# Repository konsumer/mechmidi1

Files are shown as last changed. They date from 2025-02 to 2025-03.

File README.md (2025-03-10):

This is a [RP2040-Zero](https://www.waveshare.com/rp2040-zero.htm) mechanical keyboard I designed to be a MIDI controller/sequencer and/or macro-keypad. It's made to be highly configurable & easy to modify.

> [!CAUTION]
> After assembling, I think the keys are a tiny bit too close together (spacing left/right should be doubled) and I think the RP2040 needs a board-cutout to make it lay flush. You can solder it as it is, but it makes it much harder, because it has a gap between the boards. I am currently reworking the design in Kicad, and will attempt to test another iteration.

## Features

- 20-key keypad with MX-style switches
- OLED 128x64 display
- 2 rotary encoders (each with a button)
- 20 RGB LEDs
- i2c port for adding more stuff (for example I might make a dongle for bluetooth or USB midi/keyboard/mouse/gamepad host)
- old-school MIDI in/out
- I used pi 2040, but you can use any chip, with a little modification
- designed to be easy to reflow-solder with a toaster oven, if you are manufacturing/assembling yourself
- Fully programmable with [CircuitPython](https://circuitpython.org/)
- Use [KMK](https://github.com/KMKfw/kmk_firmware) for a more keyboard-focused python-programmable firmware
- Use MIDI-focused firmware over USB, or with oldschool MIDI-out, that does sequencing
- translate USB MIDI to oldschool MIDI (no USB host, but it can interact with computer)
- pattern/song/track sequencer for sequencing drums
- pattern/song/track sequencer for sequencing notes
- arpeggio sequencer

## build/install

- order PCB & parts. Feel free to use whatever cheaper parts you can find. It pays to look around, especially with the OLED and LED chips. The key-switches are also totally up to you, but I recommend something clear, so the light shines through better. You will also need keycaps (again, clear or matte white looks nice)
- if you want to use easyeda & [jlcpcb](https://jlcpcb.com/) (it's very cheap & easy) you can disable any parts you don't need/want in BOM, and it will leave them out. For example, I didn't use the keys or 2040 they listed, I used my own (and it ended up better, I think.)
- solder components on board. [this](https://learn.sparkfun.com/tutorials/how-to-solder-castellated-mounting-holes/all) was helpful for the RP2040-Zero. Flux really helps, and a cheap USB microscope, if you have one. Basically, I fluxed it up, put a pointy tipped iron in slot, then added a lil solder, for each pin. If you are soldering the other parts, it should be easier with a toaster/hotplate, since all the parts are on one side.
- if you want classic MIDI, connect a board, like [this](https://www.amazon.com/ubld-itTM-Breakout-Board-Multi-Voltage/dp/B0BYMC926Z) to "expansion port" on board. I did this as a seperate board because I had a MIDI breakout-board laying around and I wanted it all to fit on a very small main-board. Another trick is sometimes the MIDI ports are included with other features on the board. For example [this](https://shop.m5stack.com/products/midi-unit-with-din-connector-sam2695) has MIDI DIN IN/OUT, as well as TRS MIDI ports, and has a full sound-engine built in (entire General Midi of 128 decent-sounding instruments.) Even if you don't want the sounds, the MIDI connections alone are useful, but with sounds, it makes the device even cooler!
- [install circuitpython](https://circuitpython.org/board/waveshare_rp2040_zero/) and any [libs](https://circuitpython.org/libraries) you need to "circuitpython" disk, in lib dir. You can skip this if you want arduino or some other firmware, but circuitpython is recommended initially, to test things, easily. For me, the whole circuitpython bundle was too big, so just copy [firmware](firmware). My code.py is meant to test each part initially (so you can make sure hardware/software is setup right.) I also included a lib dir, so you shouldn;t need anything else, to get started.
- move sequencer.py to code.py, and reboot, and you should have a complete device.

### expansion & hardware

At the top-left of board, there is an expansion port for MIDI/serial/i2c/power.

ports

```
[GND] (3V3) (TX) (RX) (SCL) (SDA)
```

Use this to hook up classic midi daughter-board, or any other i2c/serial thing you want.

If you need to access these pins in code or want to expand the board, here is how they are hooked up to the RP2040-Zero:

pinout

- `VCC` (3.3V) and `GND` are power. I did not expose `5V`, but you could add it to expansion-port, or you can just add a bodge-wire to chip-pin or one of the through-holes on board, if you need that. IO is best at `3.3V` for this chip, so I wanted to keep it all "easy to stay safe"
- `LED` is a neopixel-line (has 20 RGB LEDs on it, but you can add many more.) Again, a bodge-wire will be needed to add more pixels to this line, but it's fairly easy to solder one on, if you need that.
- `COL(X)`/`ROW(X)` are the keyboard-matrix
- `ROT(X)A`/`ROT(X)B`/`ROT(X)S` are the rotary-encoders (`S` is the push-down switch)
- `SDA`/`SCL` is i2c. You can add up to 127 devices to this bus (each has it's own address, and they share wires) but OLED takes up 1 slot
- `RX`/`TX` is serial or classic MIDI (with a little circuit)

### cost

You can definitely find these cheaper, if you look around. Although it's cheaper than any nice MIDI controller/sequencer/synth I found, that did what I want, super-cheap was not really a goal for me, with this project. It could be done differently, and much cheaper, I just wanted everything to work just like this, and be pretty quick/easy to assemble (it's a gift for a young-person, with not too much soldering experience.)

If you do it all my way, the per-unit cost is about $40, not including addons or whatever. A [nice midi & sound addon](https://shop.m5stack.com/products/midi-unit-with-din-connector-sam2695) is another $15.

- board with assembly - a bit cheaper in bulk, with assembly. I ordered 10, at $16 each (including shipping) and it has most of the parts on the board (no RP2040 or keys.) In much larger quantites, the price goes way down, and you can shop around for cheapest board (I went with easiest.) I can sell you a pre-populated board for $16 (not including shipping to you) until I run out. I currently have 5 of these on-hand. You can also get the price down by etching/assembling yourself, and just ordering parts (in bulk) but some of the parts are a bit tricky to solder by hand (a toaster would work better for the LEDs and diodes.) $16 seems pretty cheap to me, and the hardest soldering is done, and it's mostly all built, but some nice & fun soldering is left.
- RP2040-Zero - I bought [3 for $20](https://www.amazon.com/gp/product/B0BZ8D4CJM/?th) and got it the next day, but they are definitely way cheaper elsewhere (check aliexpress/etc) if you are willing to wait for shipping, especially if you are buying them in bulk (they are very useful for all kinds of things.)
- mech key switches - I used [these nice ones](https://www.amazon.com/gp/product/B0CDW74TX3), $20 for 45 (enough for 2 devices) but you can find these much cheaper.
- keycaps - I used [these](https://www.amazon.com/gp/product/B0CQ2XD4WT). $12 for 20, or $31 for 100. XDA is less "scuplted" than Cherry, but either will work fine.

To build 10, it's about $260 ($26 per unit):

- boards $160 - go cheaper by making your own, or printing/assembling more at a time. Assembly is not very expensive compared to the PCB, I have found, so it might be worth it to add $2 per-unit and save yourself some time/effort.
- key switches $84 - you can definitely find these cheaper on aliexpress
- [10 2040s](https://www.aliexpress.us/item/3256806922860079.html) $15
- order some super-cheap keycaps that will work for you. clear is best, but white will work fine, too. If you are ok with lettering on them, you can reuse a super-cheap macropad-set.

You could get this even cheaper with greater bulk-quantities, and shopping around, though.

### ideas for cheaper

- Use membrane-keys (silicone buttons over PCB traces) instead of mech-keys
- drop LEDs, or use single-color
- drop OLED
- drop rotary-encoders
- try to get all parts on single-side (for cheaper/easier-to-make-at-home PCB)

## Modify

This thing is meant to be hacked!

### hardware

- Install [EasyEDA](https://easyeda.com/)
- move things in schematice however you want, or add/remove anyhting you like. Make sure to update PCB (alt-I.) The 2040 is maxed-out for GPIO, but the layout should be simple enough to modify (unroute all, then do your business with nets like `COL0`, `ROW0`, etc, then auto-route.) I recommend replacing the chip wityh somerthing bigger if you want to do ther stuff (see [picoadk](https://www.tindie.com/products/datanoisetv/picoadk-audio-development-kit-raspberry-rp2040/) for a nice 2040 firmware for larger pico, with sound-generatin in mind!)

### software

If you want to change how the software works, I have created a [simple lib](firmware/midimech1.py) to interact with the existing hardware in [CircuitPython](https://circuitpython.org/). See how I use it in [sequencer.py](firmware/sequencer.py). If you change the hardware, you will probly need to also modify these.

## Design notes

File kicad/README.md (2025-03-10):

This is Kicad source for the hardware.

You should install these 2 libs, if you want to edit things:

- [ScottoKeebs](https://github.com/joe-scotto/scottokeebs/tree/main/Extras/ScottoKicad)
- [RP2040-Zero-Kicad](https://github.com/CountParadox/RP2040-Zero-Kicad)

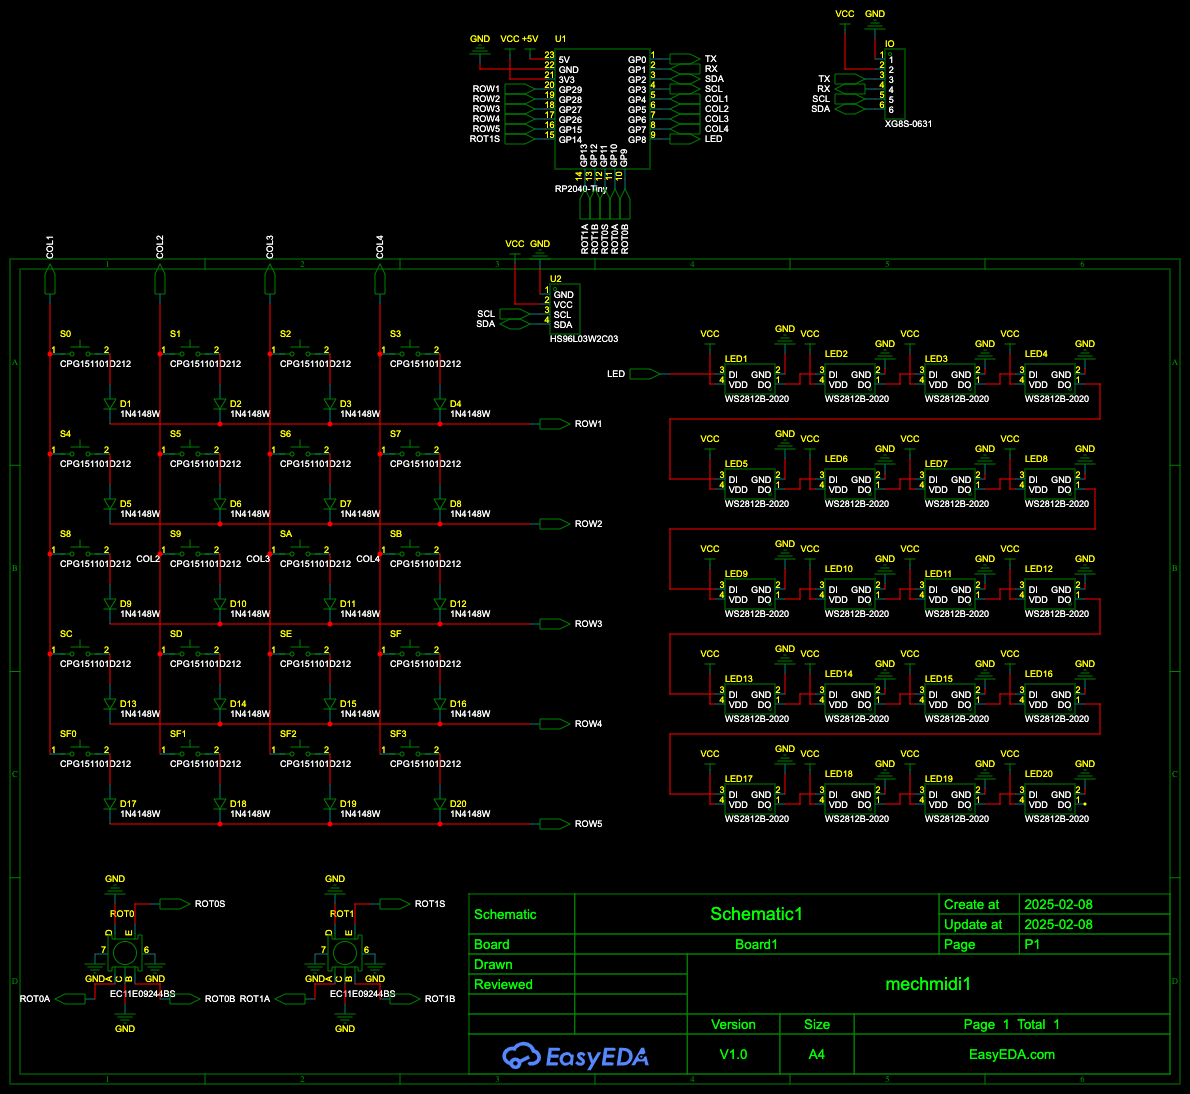
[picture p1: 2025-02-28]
schematic.png

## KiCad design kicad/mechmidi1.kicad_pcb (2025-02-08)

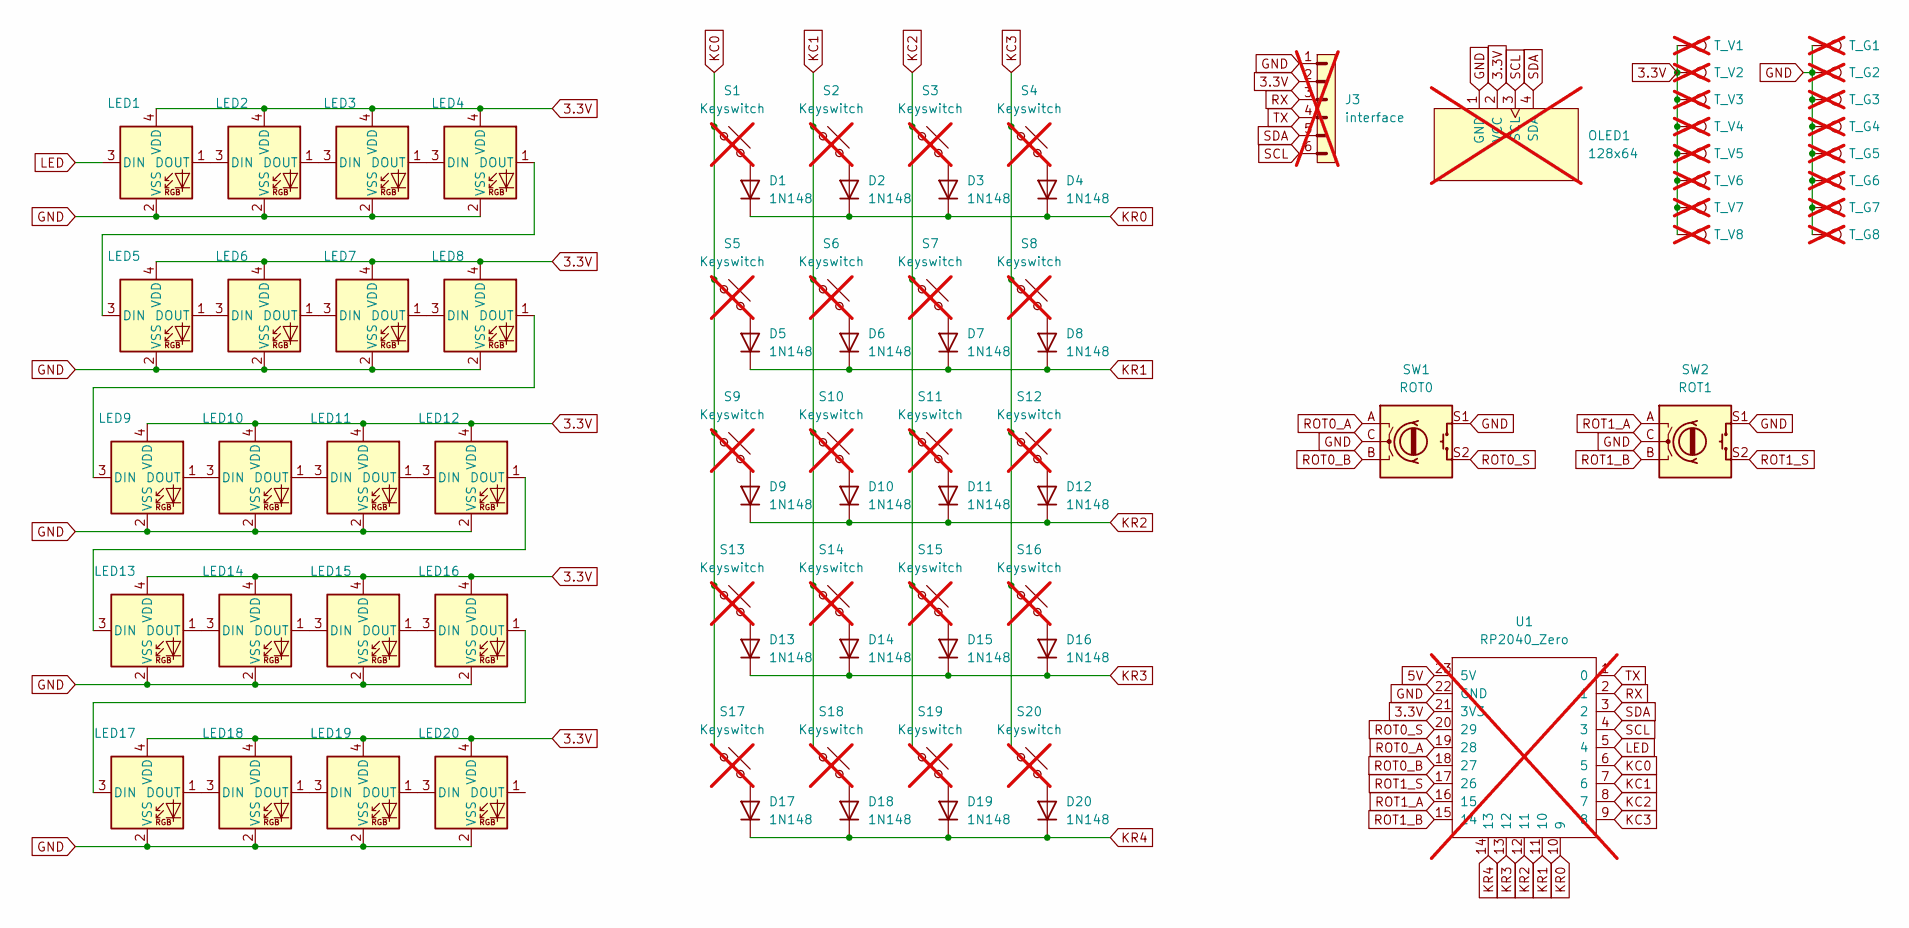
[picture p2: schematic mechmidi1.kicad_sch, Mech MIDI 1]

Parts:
D1, D2, D3, D4, D5, D6, D7, D8, D9, D10, D11, D12, D13, D14, D15, D16, D17, D18, D19, D20: 1N148; D_SOD-123
J3: interface; PinHeader_1x06_P2.54mm_Vertical; not fitted
LED1, LED2, LED3, LED4, LED5, LED6, LED7, LED8, LED9, LED10, LED11, LED12, LED13, LED14, LED15, LED16, LED17, LED18, LED19, LED20: WS2812B-2020; LED_WS2812B-2020_PLCC4_2.0x2.0mm
OLED1: 128x64; OLED_128x64; not fitted
S1, S2, S3, S4, S5, S6, S7, S8, S9, S10, S11, S12, S13, S14, S15, S16, S17, S18, S19, S20: Keyswitch; MX_PCB_1.00u; not fitted
SW1: ROT0; RotaryEncoder_Alps_EC11E-Switch_Vertical_H20mm
SW2: ROT1; RotaryEncoder_Alps_EC11E-Switch_Vertical_H20mm
T_G1, T_G2, T_G3, T_G4, T_G5, T_G6, T_G7, T_G8: TestPoint; Pin_D0.7mm_L6.5mm_W1.8mm_FlatFork; not fitted
T_V1, T_V2, T_V3, T_V4, T_V5, T_V6, T_V7, T_V8: TestPoint; Pin_D0.7mm_L6.5mm_W1.8mm_FlatFork; not fitted
U1: RP2040_Zero; not fitted

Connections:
3.3V: J3.2, LED1.4 (VDD), LED2.4 (VDD), LED3.4 (VDD), LED4.4 (VDD), LED5.4 (VDD), LED6.4 (VDD), LED7.4 (VDD), LED8.4 (VDD), LED9.4 (VDD), LED10.4 (VDD), LED11.4 (VDD), LED12.4 (VDD), LED13.4 (VDD), LED14.4 (VDD), LED15.4 (VDD), LED16.4 (VDD), LED17.4 (VDD), LED18.4 (VDD), LED19.4 (VDD), LED20.4 (VDD), OLED1.2 (VCC), T_V1.1, T_V2.1, T_V3.1, T_V4.1, T_V5.1, T_V6.1, T_V7.1, T_V8.1, U1.21 (3V3)
5V: U1.23 (5V)
GND: J3.1, LED1.2 (VSS), LED2.2 (VSS), LED3.2 (VSS), LED4.2 (VSS), LED5.2 (VSS), LED6.2 (VSS), LED7.2 (VSS), LED8.2 (VSS), LED9.2 (VSS), LED10.2 (VSS), LED11.2 (VSS), LED12.2 (VSS), LED13.2 (VSS), LED14.2 (VSS), LED15.2 (VSS), LED16.2 (VSS), LED17.2 (VSS), LED18.2 (VSS), LED19.2 (VSS), LED20.2 (VSS), OLED1.1 (GND), SW1.C, SW1.S1, SW2.C, SW2.S1, T_G1.1, T_G2.1, T_G3.1, T_G4.1, T_G5.1, T_G6.1, T_G7.1, T_G8.1, U1.22 (GND)
KC0: S1.1, S5.1, S9.1, S13.1, S17.1, U1.6 (5)
KC1: S2.1, S6.1, S10.1, S14.1, S18.1, U1.7 (6)
KC2: S3.1, S7.1, S11.1, S15.1, S19.1, U1.8 (7)
KC3: S4.1, S8.1, S12.1, S16.1, S20.1, U1.9 (8)
KR0: D1.1 (K), D2.1 (K), D3.1 (K), D4.1 (K), U1.10 (9)
KR1: D5.1 (K), D6.1 (K), D7.1 (K), D8.1 (K), U1.11 (10)
KR2: D9.1 (K), D10.1 (K), D11.1 (K), D12.1 (K), U1.12 (11)
KR3: D13.1 (K), D14.1 (K), D15.1 (K), D16.1 (K), U1.13 (12)
KR4: D17.1 (K), D18.1 (K), D19.1 (K), D20.1 (K), U1.14 (13)
LED: LED1.3 (DIN), U1.5 (4)
unnamed: D1.2 (A), S1.2
unnamed: D2.2 (A), S2.2
unnamed: D3.2 (A), S3.2
unnamed: D4.2 (A), S4.2
unnamed: D5.2 (A), S5.2
unnamed: D6.2 (A), S6.2
unnamed: D7.2 (A), S7.2
unnamed: D8.2 (A), S8.2
unnamed: D9.2 (A), S9.2
unnamed: D10.2 (A), S10.2
unnamed: D11.2 (A), S11.2
unnamed: D12.2 (A), S12.2
unnamed: D13.2 (A), S13.2
unnamed: D14.2 (A), S14.2
unnamed: D15.2 (A), S15.2
unnamed: D16.2 (A), S16.2
unnamed: D17.2 (A), S17.2
unnamed: D18.2 (A), S18.2
unnamed: D19.2 (A), S19.2
unnamed: D20.2 (A), S20.2
unnamed: LED1.1 (DOUT), LED2.3 (DIN)
unnamed: LED2.1 (DOUT), LED3.3 (DIN)
unnamed: LED3.1 (DOUT), LED4.3 (DIN)
unnamed: LED4.1 (DOUT), LED5.3 (DIN)
unnamed: LED5.1 (DOUT), LED6.3 (DIN)
unnamed: LED6.1 (DOUT), LED7.3 (DIN)
unnamed: LED7.1 (DOUT), LED8.3 (DIN)
unnamed: LED8.1 (DOUT), LED9.3 (DIN)
unnamed: LED9.1 (DOUT), LED10.3 (DIN)
unnamed: LED10.1 (DOUT), LED11.3 (DIN)
unnamed: LED11.1 (DOUT), LED12.3 (DIN)
unnamed: LED12.1 (DOUT), LED13.3 (DIN)
unnamed: LED13.1 (DOUT), LED14.3 (DIN)
unnamed: LED14.1 (DOUT), LED15.3 (DIN)
unnamed: LED15.1 (DOUT), LED16.3 (DIN)
unnamed: LED16.1 (DOUT), LED17.3 (DIN)
unnamed: LED17.1 (DOUT), LED18.3 (DIN)
unnamed: LED18.1 (DOUT), LED19.3 (DIN)
unnamed: LED19.1 (DOUT), LED20.3 (DIN)
ROT0_A: SW1.A, U1.19 (28)
ROT0_B: SW1.B, U1.18 (27)
ROT0_S: SW1.S2, U1.20 (29)
ROT1_A: SW2.A, U1.16 (15)
ROT1_B: SW2.B, U1.15 (14)
ROT1_S: SW2.S2, U1.17 (26)
RX: J3.3, U1.2 (1)
SCL: J3.6, OLED1.3 (SCL), U1.4 (3)
SDA: J3.5, OLED1.4 (SDA), U1.3 (2)
TX: J3.4, U1.1 (0)

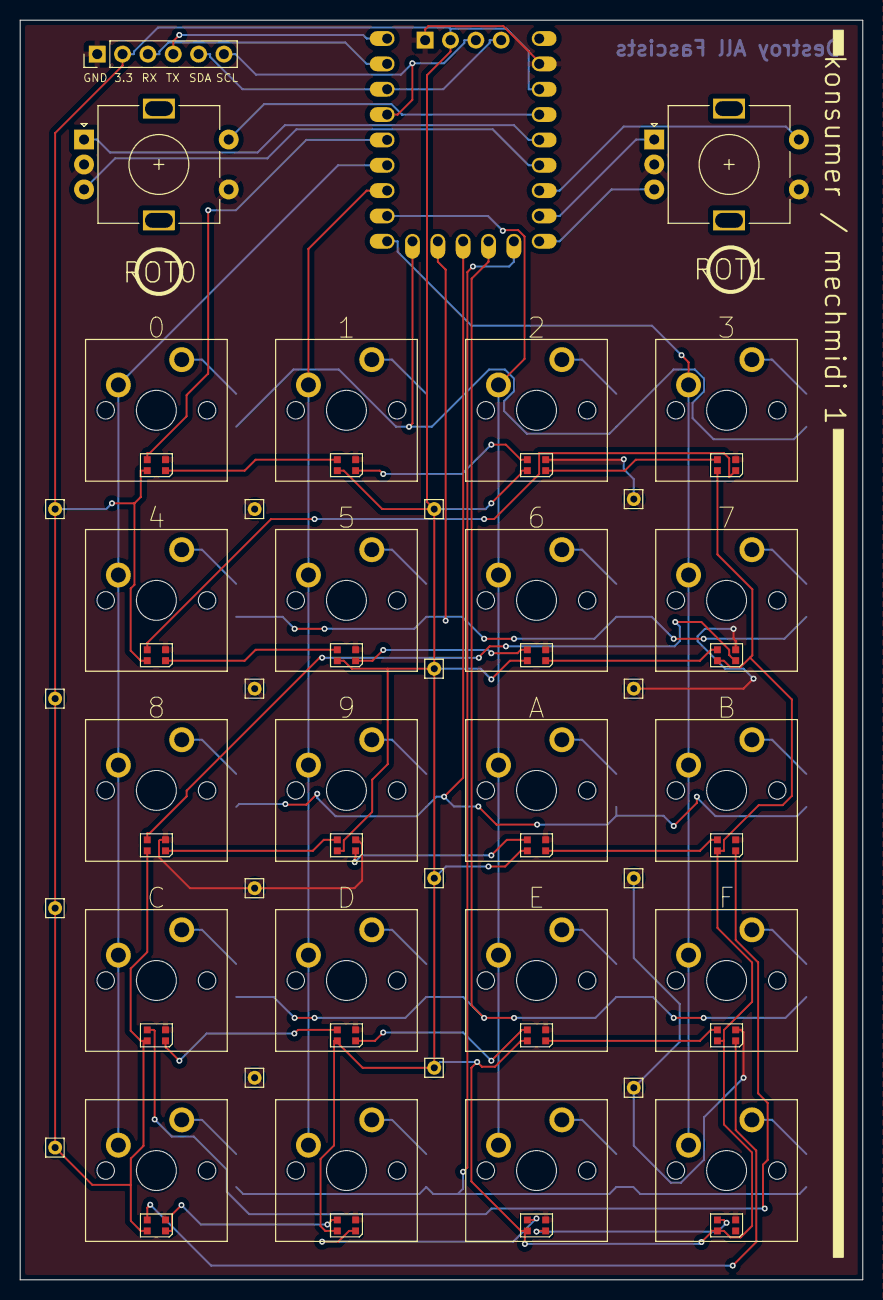
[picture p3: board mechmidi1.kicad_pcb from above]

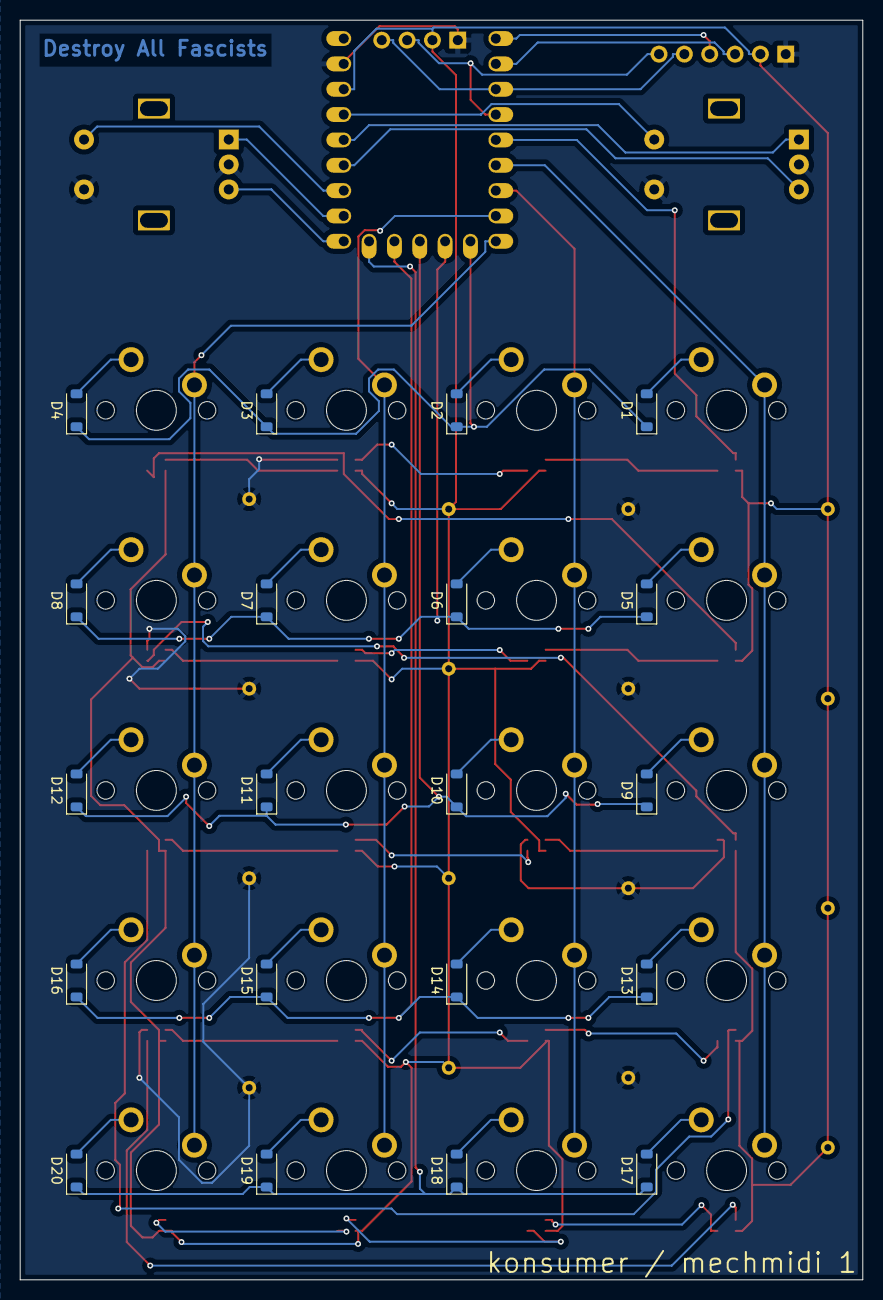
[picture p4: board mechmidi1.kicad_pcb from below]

Board: 2 copper layers, 84.4 x 126.2 mm, 81 parts (21 on the bottom side), 61 nets.

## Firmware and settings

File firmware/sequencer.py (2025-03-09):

from time import sleep, monotonic_ns
import board
import busio
from digitalio import Direction, DigitalInOut, Pull
from rotaryio import IncrementalEncoder
from keypad import KeyMatrix
import neopixel
import displayio
import terminalio
from adafruit_display_text import label
from i2cdisplaybus import I2CDisplayBus
from adafruit_led_animation.color import RAINBOW, RED, YELLOW, ORANGE, GREEN, TEAL, CYAN, BLUE, PURPLE, MAGENTA, WHITE, BLACK, GOLD, PINK, AQUA, JADE, AMBER, OLD_LACE
from adafruit_led_animation.animation.rainbowcomet import RainbowComet
from adafruit_led_animation.animation.sparklepulse import SparklePulse
import adafruit_displayio_ssd1306
import adafruit_midi
import usb_midi
from adafruit_midi.note_on import NoteOn
from adafruit_midi.note_off import NoteOff
from adafruit_midi.control_change import ControlChange
from adafruit_midi.program_change import ProgramChange
from adafruit_midi.system_exclusive import SystemExclusive
import saminfo
from mechmidi1 import Menu,ROT0S,ROT0A,ROT0B,ROT1S,ROT1A,ROT1B,SDA,SCL,LED,ROW1,ROW2,ROW3,ROW4,ROW5,COL1,COL2,COL3,COL4,TX

### setup

# setup USB midi on all channels
midi = adafruit_midi.MIDI(midi_in=usb_midi.ports[0] )

# this is for SAM2695 on TX
uart = busio.UART(tx=TX, baudrate=31250, bits=8, parity=None, stop=1)
sam = adafruit_midi.MIDI(midi_out=uart, out_channel=0)
sam.send(SystemExclusive([0x7e, 0x7f], [0x09, 0x01])) # Reset
sam.send(SystemExclusive([0x7f, 0x7f, 0x04], [0x01, 0x00, 123 & 0x7f])) # Volume 123

# setup i2c and OLED
displayio.release_displays()
i2c = busio.I2C(SCL, SDA, frequency=1_000_000)
display = adafruit_displayio_ssd1306.SSD1306(I2CDisplayBus(i2c, device_address=0x3C), width=128, height=64, rotation=180)

screen = displayio.Group()
display.root_group = screen

def logo_display():
  with open("logo.bmp", "rb") as logo_file:
      logo_bmp = displayio.OnDiskBitmap(logo_file)
      logo = displayio.TileGrid(
        logo_bmp,
        pixel_shader = getattr(logo_bmp, 'pixel_shader', displayio.ColorConverter()),
        x=25
      )
      screen.append(logo)
      display.refresh()
      sleep(1)
      logo.hidden = True

# setup RGB LEDs
pixels = neopixel.NeoPixel(
    LED,
    20,
    brightness=0.2,
    auto_write=False,
    pixel_order=neopixel.GRB
)
pixels.fill(0)
pixels.show()

# setup rotary-encoders
rot = [
    IncrementalEncoder(ROT0A, ROT0B, divisor=2),
    IncrementalEncoder(ROT1A, ROT1B, divisor=2)
]

rotb = [
    DigitalInOut(ROT0S),
    DigitalInOut(ROT1S)
]

rotb[0].direction=Direction.INPUT
rotb[0].pull=Pull.UP
rotb[1].direction=Direction.INPUT
rotb[1].pull=Pull.UP

# setup keypad
keys = KeyMatrix(row_pins=(ROW1,ROW2,ROW3,ROW4,ROW5), column_pins=(COL1,COL2,COL3,COL4))

# setup text-display
t = label.Label(terminalio.FONT, text="", color=0xffffff, x=0, y=5)
screen.append(t)

### /setup


instruments = []
def instruments_load():
  # initially just set instrument 0-F to 0-F patch
  for i in range(16):
    instruments.append((saminfo.patches[i], i))
  try:
    with open("instruments.txt") as f:
      for line in f.readlines():
        (c,p) = line.strip().split(':')
        if c and p:
          i = int('0x' + p)
          instruments[int('0x' + c)] = (saminfo.patches[i], i)
  except:
    pass




# TODO: check if we can save (normally we can't, if CIRCUITPYTHON is mounted)
def instruments_save(channel, patch):
  t.text=f"To persist:\nadd {hstring(channel)}:{hstring(patch)} in instruments.txt"
  sleep(3)

# convert number to nice hex
def hstring(n):
  return hex(n).replace('0x', '').upper()


# initial song-loading is a bit jenk, but I will add more, later
from songs import aaaaaa as song
current_pattern = 0
current_instrument = 0
song_position = 0
pattern_position = 0
song_playing = True
function_buttons = [0,0,0,0]

play_on_press = True

# simple drum machine
def drum_machine():
  global current_instrument
  global current_pattern
  global song
  global song_playing

  rot[0].position = song.bpm

  pixels.fill(BLACK)
  pixels.show()
  running = True
  t.text = f"BPM: {song.bpm}\n{saminfo.drum_names[current_instrument]}"
  
  pixels.fill(BLACK)
  pixels[16] = (0x30, 0x30, 0x30)
  pixels[17] = (0x10, 0x30, 0x30)
  pixels[18] = (0x30, 0x10, 0x30)
  pixels[19] = (0x30, 0x30, 0x10)

  position = 0
  start_time = monotonic_ns()
  
  while running:
    song.bpm = rot[0].position
    seconds_per_beat = 15_000_000_000 / song.bpm
    
    for i,v in enumerate(song.beat_patterns[current_pattern][current_instrument]):
      if v:
        pixels[i] = RAINBOW[current_instrument % len(RAINBOW)]
      else:
         pixels[i] = BLACK
    e = keys.events.get()
    if e:
      if e.key_number > 15:
        k = e.key_number - 16
        if e.pressed:
          function_buttons[k] = 1
        else:
          function_buttons[k] = 0
      else:
        if function_buttons[0] & e.pressed:
          current_instrument = e.key_number
        else:
          if e.pressed:
            if play_on_press:
              sam.send(NoteOn(note=current_instrument+35, velocity=100), channel=9)
            if song.beat_patterns[current_pattern][current_instrument][e.key_number]:
              song.beat_patterns[current_pattern][current_instrument][e.key_number] = 0
            else:
              song.beat_patterns[current_pattern][current_instrument][e.key_number] = 1

    if function_buttons[0]:
      t.text = f"BPM: {song.bpm}\n{saminfo.drum_names[current_instrument]}\nChoose Instrument"
    else:
      t.text = f"BPM: {song.bpm}\n{saminfo.drum_names[current_instrument]}"

    if song_playing:
      ct = monotonic_ns()
      if (ct - start_time) > seconds_per_beat:
        start_time = ct
        position = (position + 1) % 16
        for i,v in enumerate(song.beat_patterns[current_pattern]):
          if v[position]:
            sam.send(NoteOn(note=i+35, velocity=127), channel=9)

      pixels[position] = (60, 60, 60)

    if not rotb[0].value:
      running = False

    pixels.show()
  pixels.fill(BLACK)
  pixels.show()
  sleep(0.2)
  currentMode = MenuMain(t, rot[0], rotb[0])



class MenuChooseInstrument(Menu):
  def __init__(self, channelnum, textArea, rot, button):
    items = []
    for i,v in enumerate(saminfo.patches):
      items.append(f"{hstring(i)} {v}")
    items.append("<- Back")
    self.channelnum = channelnum
    super(MenuInstruments, self).__init__(f"Channel {hstring(channelnum)}", items, textArea, rot, button)
    self.rot.position = instruments[channelnum][1]
    self.oldpos = -1
  
  def select(self, position):
    global currentMode
    pixels.fill(BLACK)
    pixels.show()
    sleep(0.2)
    if position != 128:
      instruments[self.channelnum] = (saminfo.patches[position], position)
      instruments_save(self.channelnum, position)
    currentMode = MenuInstruments(self.t, self.rot, self.button)

  # let user play instrument when they are choosing
  def show(self):
    super(MenuInstruments, self).show()
    position = self.rot.position % len(self.items)
    if position < 128:
      if (position != self.oldpos):
        sam.send(ProgramChange(patch=position), channel=0)
        self.oldpos = position
      e = keys.events.get()
      if e and e.key_number < 16:
        if e.pressed:
          pixels[e.key_number] = RED
          sam.send(NoteOn(note=e.key_number+48, velocity=100), channel=0)
          pixels.show()
        else:
          pixels[e.key_number] = BLACK
          sam.send(NoteOff(note=e.key_number+48), channel=0)
          pixels.show()

class MenuInstruments(Menu):
  def __init__(self, textArea, rot, button):
    items = []
    for (i,v) in enumerate(instruments):
      items.append(f"{hstring(i)}:{hstring(v[1])} {v[0]}")
    items.append("<- Back")
    super(MenuInstruments, self).__init__("Instruments", items, textArea, rot, button)
    self.oldpos = -1
  
  def select(self, position):
    global currentMode
    pixels.fill(BLACK)
    pixels.show()
    sleep(0.2)
    if position == 16:
      currentMode = MenuSettings(self.t, self.rot, self.button)
    else:
      currentMode = MenuChooseInstrument(position, self.t, self.rot, self.button)

  # let user play instrument when they are choosing
  def show(self):
    super(MenuInstruments, self).show()
    position = self.rot.position % len(self.items)
    if position < 16:
      if (position != self.oldpos):
        sam.send(ProgramChange(patch=instruments[position][1]), channel=0)
        self.oldpos = position
      e = keys.events.get()
      if e and e.key_number < 16:
        if e.pressed:
          pixels[e.key_number] = RED
          sam.send(NoteOn(note=e.key_number+48, velocity=100), channel=0)
          pixels.show()
        else:
          pixels[e.key_number] = BLACK
          sam.send(NoteOff(note=e.key_number+48), channel=0)
          pixels.show()

class MenuSettings(Menu):
  def __init__(self, textArea, rot, button):
    super(MenuMain, self).__init__("Settings", ["Instruments", "<- Back"], textArea, rot, button)
  
  def select(self, position):
    global currentMode
    sleep(0.2)
    if position == 0:
      currentMode = MenuInstruments(self.t, self.rot, self.button)
    if position == 1:
      currentMode = MenuMain(self.t, self.rot, self.button)


class MenuMain(Menu):
  def __init__(self, textArea, rot, button):
    super(MenuMain, self).__init__("mechmidi", ["Beat", "Melody", "Settings"], textArea, rot, button)

  def select(self, position):
    global currentMode
    sleep(0.2)
    if position == 0:
      drum_machine()
    if position == 2:
      currentMode = MenuSettings(self.t, self.rot, self.button)


instruments_load()
logo_display()


currentMode = MenuMain(t, rot[0], rotb[0])
while True:
  currentMode.show()

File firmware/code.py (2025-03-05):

from time import sleep
import board
import busio
from digitalio import Direction, DigitalInOut, Pull
from rotaryio import IncrementalEncoder
from keypad import KeyMatrix
import neopixel
import displayio
import terminalio
from adafruit_display_text import label
from i2cdisplaybus import I2CDisplayBus
from adafruit_led_animation.color import RAINBOW, RED, YELLOW, ORANGE, GREEN, TEAL, CYAN, BLUE, PURPLE, MAGENTA, WHITE, BLACK, GOLD, PINK, AQUA, JADE, AMBER, OLD_LACE
from adafruit_led_animation.animation.rainbowcomet import RainbowComet
from adafruit_led_animation.animation.sparklepulse import SparklePulse
import adafruit_displayio_ssd1306
import adafruit_midi
import usb_midi
from adafruit_midi.note_on import NoteOn
from adafruit_midi.note_off import NoteOff
from adafruit_midi.control_change import ControlChange
from adafruit_midi.program_change import ProgramChange
from adafruit_midi.system_exclusive import SystemExclusive
import saminfo
from mechmidi1 import Menu,ROT0S,ROT0A,ROT0B,ROT1S,ROT1A,ROT1B,SDA,SCL,LED,ROW1,ROW2,ROW3,ROW4,ROW5,COL1,COL2,COL3,COL4,TX

# setup USB midi on all channels
midi = adafruit_midi.MIDI(midi_in=usb_midi.ports[0] )

# this is for SAM2695 on TX
uart = busio.UART(tx=TX, baudrate=31250, bits=8, parity=None, stop=1)
sam = adafruit_midi.MIDI(midi_out=uart, out_channel=0)
sam.send(SystemExclusive([0x7e, 0x7f], [0x09, 0x01])) # Reset
sam.send(SystemExclusive([0x7f, 0x7f, 0x04], [0x01, 0x00, 123 & 0x7f])) # Volume 123

# setup i2c and OLED
displayio.release_displays()
i2c = busio.I2C(SCL, SDA, frequency=1_000_000)
display = adafruit_displayio_ssd1306.SSD1306(I2CDisplayBus(i2c, device_address=0x3C), width=128, height=64, rotation=180)

screen = displayio.Group()
display.root_group = screen

def logo_display():
  with open("logo.bmp", "rb") as logo_file:
      logo_bmp = displayio.OnDiskBitmap(logo_file)
      logo = displayio.TileGrid(
          logo_bmp,
          pixel_shader = getattr(logo_bmp, 'pixel_shader', displayio.ColorConverter()),
          x=25
      )
      screen.append(logo)
      display.refresh()
      sleep(1)
      logo.hidden = True
logo_display()

# setup RGB LEDs
pixels = neopixel.NeoPixel(
    LED,
    20,
    brightness=0.2,
    auto_write=False,
    pixel_order=neopixel.GRB
)
pixels.fill(0)
pixels.show()

# setup rotary-encoders
rot = [
    IncrementalEncoder(ROT0A, ROT0B, divisor=2),
    IncrementalEncoder(ROT1A, ROT1B, divisor=2)
]

rotb = [
    DigitalInOut(ROT0S),
    DigitalInOut(ROT1S)
]

rotb[0].direction=Direction.INPUT
rotb[0].pull=Pull.UP
rotb[1].direction=Direction.INPUT
rotb[1].pull=Pull.UP

# setup keypad
keys = KeyMatrix(row_pins=(ROW1,ROW2,ROW3,ROW4,ROW5), column_pins=(COL1,COL2,COL3,COL4))

# setup text-display
t = label.Label(terminalio.FONT, text="", color=0xffffff, x=0, y=5)
screen.append(t)

###


# OLED makes SAM a bit delayed, so I don't update screen while it's running
def demo_midisam(t):
  # you can map patches to channels like this
  sam.send(ProgramChange(patch=0), channel=0) # Piano
  sam.send(ProgramChange(patch=17), channel=1) # Drawbar Organ

  t.text = "Send USB MIDI\n"
  while True:
    m = midi.receive()
    if m:
      # forward USB MID to same and show stuff on screen
      if isinstance(m, NoteOff):
        sam.send(NoteOff(note=m.note), channel=m.channel)
      if isinstance(m, NoteOn):
        sam.send(NoteOn(note=m.note), channel=m.channel)
      if isinstance(m, ControlChange):
        sam.send(ControlChange(control=m.control, value=m.value), channel=m.channel)
      if isinstance(m, ProgramChange):
        sam.send(ProgramChange(patch=m.patch), channel=m.channel)
    if not rotb[0].value and not rotb[1].value:
      break
  sleep(0.2)

# Just show MIDI stuff on screen
def demo_midi(t):
  t.text = "Send USB MIDI\n"
  while True:
    m = midi.receive()
    if m:
      # forward USB MID to same and show stuff on screen
      if isinstance(m, NoteOff):
        t.text = f"MIDI\nnote:{m.note}\nvelocity:{m.velocity}\nchannel:{m.channel}"
      if isinstance(m, NoteOn):
        t.text = f"MIDI\nnote:{m.note}\nvelocity:{m.velocity}\nchannel:{m.channel}"
      if isinstance(m, ControlChange):
        t.text = f"MIDI\ncontrol:{m.control}\nvalue:{m.value}\nchannel:{m.channel}"
      if isinstance(m, ProgramChange):
        t.text = f"MIDI\nprogram:{m.patch}\nchannel:{m.channel}"
    if not rotb[0].value and not rotb[1].value:
      break
  sleep(0.2)

# just play piano on SAM
# notes start at C3
def demo_piano(t):
  pixels.fill(BLACK)
  pixels.show()
  rot[0].position = 0
  inst = 0
  oldval = 0
  t.text = f"({inst+1}) {saminfo.patches[inst]}\nPress keys to play\nPress both rotaries\nto exit\n"
  sam.send(ProgramChange(patch=inst), channel=0) # set proagram to rot position
  while True:
    inst = rot[0].position % 128
    if oldval != inst:
      t.text = f"({inst+1}) {saminfo.patches[inst]}\nPress keys to play\nPress both rotaries\nto exit\n"
      sam.send(ProgramChange(patch=inst), channel=0) # set proagram to rot position
      oldval = inst
    e = keys.events.get()
    if e:
      if e.pressed:
        pixels[e.key_number] = RED
        sam.send(NoteOn(note=e.key_number+48, velocity=100), channel=0)
        pixels.show()
      else:
        pixels[e.key_number] = BLACK
        sam.send(NoteOff(note=e.key_number+48), channel=0)
        pixels.show()
    if not rotb[0].value and not rotb[1].value:
      break
  pixels.fill(BLACK)
  pixels.show()
  sleep(0.2)

# just play drums on SAM
def demo_drums(t):
  pixels.fill(BLACK)
  pixels.show()
  rot[0].position = 0
  inst = 0
  oldval = 0
  t.text = f"{saminfo.drums[inst]}\nPress keys to play\nPress both rotaries\nto exit\n"
  sam.send(ProgramChange(patch=saminfo.drum_programs[inst]), channel=9) # set proagram to rot position
  while True:
    inst = rot[0].position % 5
    if oldval != inst:
      t.text = f"{saminfo.drums[inst]}\nPress keys to play\nPress both rotaries\nto exit\n"
      sam.send(ProgramChange(patch=saminfo.drum_programs[inst]), channel=9) # set proagram to rot position
      oldval = inst
    e = keys.events.get()
    if e:
      if e.pressed:
        pixels[e.key_number] = GREEN
        sam.send(NoteOn(note=e.key_number+36, velocity=100), channel=9)
        pixels.show()
      else:
        pixels[e.key_number] = BLACK
        sam.send(NoteOff(note=e.key_number+36), channel=9)
        pixels.show()
    if not rotb[0].value and not rotb[1].value:
      break
  pixels.fill(BLACK)
  pixels.show()
  sleep(0.2)

def demo_input():
  while True:
    t.text = f"INPUT\nPress R0+R1 to exit\nR0: {rot[0].position} {not rotb[0].value}\nR1: {rot[1].position} {not rotb[1].value}"
    e = keys.events.get()
    if e:
        if e.pressed:
            pixels[e.key_number] = GREEN
        else:
            pixels[e.key_number] = BLUE
        pixels.show()
    if not rotb[0].value and not rotb[1].value:
      break
  pixels.fill(0)
  pixels.show()
  sleep(0.2)

# LED demos that wait for button-press
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

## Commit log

2025-02-06 move all the things off main board
    [mechmidi1.kicad_pcb, mechmidi1.kicad_sch]
2025-02-08 working on new PCB ideas
    [mechmidi1-bom.csv, mechmidi1.kicad_pcb, mechmidi1.kicad_sch]
2025-02-28 schematic image
2025-03-01 More pin explanations
2025-03-02 reworked firmware a bit
    [sequencer.py]
2025-03-05 reset rotary on load
    [code.py]
2025-03-10 moving back to kicad
